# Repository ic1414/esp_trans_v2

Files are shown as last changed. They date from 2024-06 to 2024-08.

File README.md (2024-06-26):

# esp_trans_v2

- [视频介绍](https://www.bilibili.com/video/BV1F94y157EU/?spm_id_from=333.999.0.0)（[旧版遥控](https://www.bilibili.com/video/BV1n44y1s7gA/?spm_id_from=333.999.0.0)）
- [视频组装](https://www.bilibili.com/video/BV1uH4y1w7Zv/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)
- [software doc](./doc/software_tut.md)  
- [hardware doc](./doc/hardware_tut.md)   

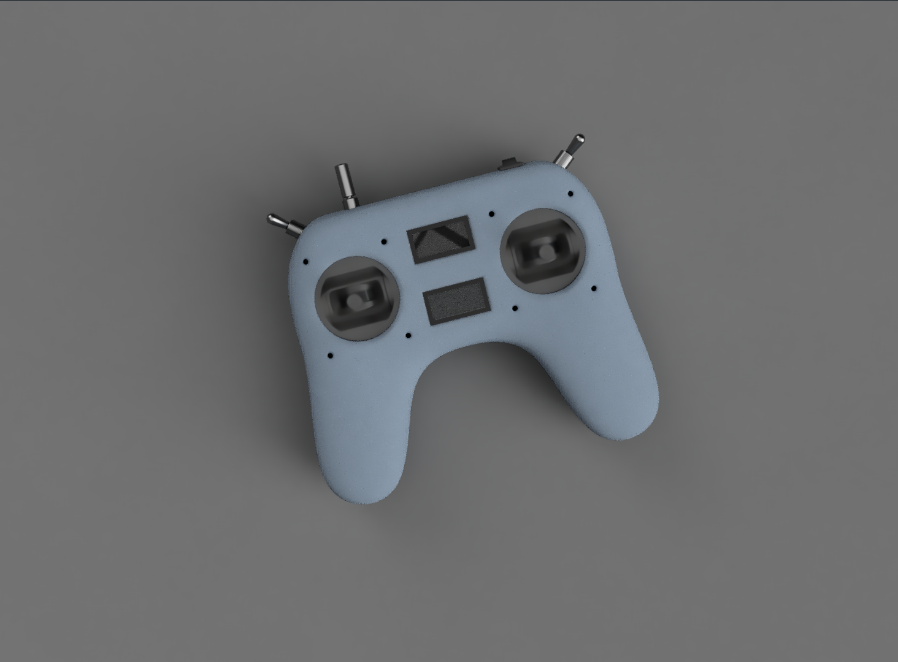
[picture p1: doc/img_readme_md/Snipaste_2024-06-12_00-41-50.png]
esp_trans_v2


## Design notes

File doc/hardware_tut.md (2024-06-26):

- [一些图片](#一些图片)
- [一些文件](#一些文件)
- [焊盘&丝印](#焊盘丝印)
- [pcb 接线图](#pcb-接线图)
- [零件排线长度](#零件排线长度)
- [制作步骤（参考）](#制作步骤参考)
- [注意事项](#注意事项)
- [end](#end)

## 一些图片



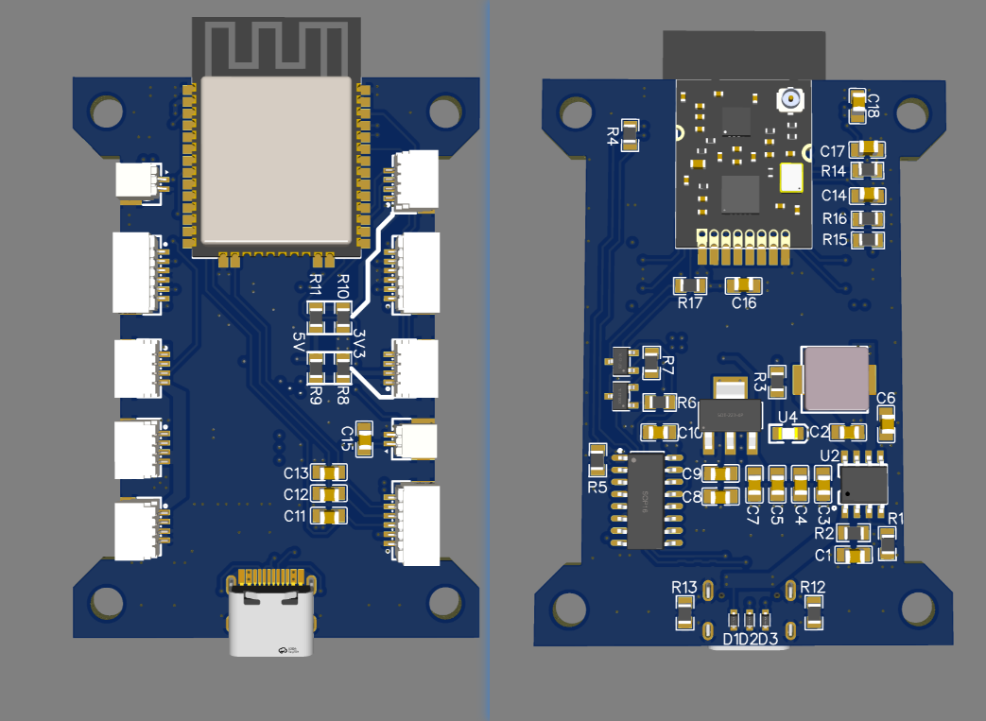
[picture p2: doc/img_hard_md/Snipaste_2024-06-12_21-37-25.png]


## 一些文件

- [购物清单](../pcb/esp_trans_v2_material.xlsx)  
- [3d模型-上半身](../3d%20model/top2.stl)，[3d模型-下半身](../3d%20model/bot2.stl)
- [立创eda 原理图](../pcb/LCEDA_schematic_esp_trans_v2.json)，[pdf 原理图](../pcb/pdf_schematic_esp_trans_v2.pdf)
- [立创eda pcb 源文件](../pcb/LCEDA_PCB_esp_trans_v2.json)，[gerber文件](../pcb/Gerber_PCB_esp_trans_v2.zip)  
- [bom表](../pcb/esp_trans_v2_bom_lite.xlsx)  

## 焊盘&丝印
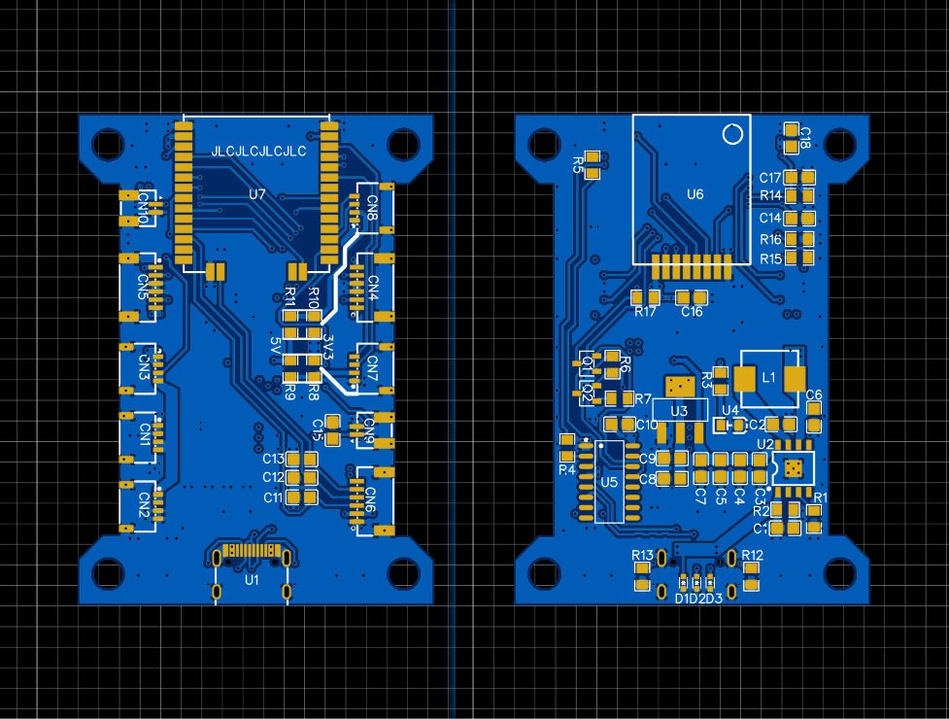
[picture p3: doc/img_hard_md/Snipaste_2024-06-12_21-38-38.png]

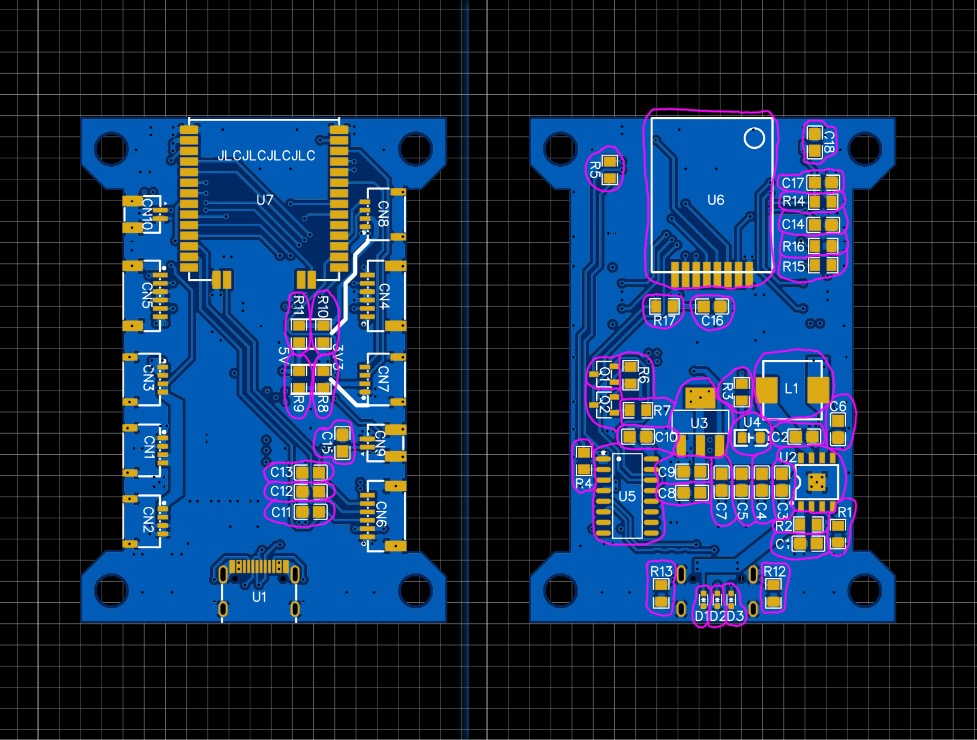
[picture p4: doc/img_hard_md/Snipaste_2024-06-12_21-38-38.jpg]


## pcb 接线图

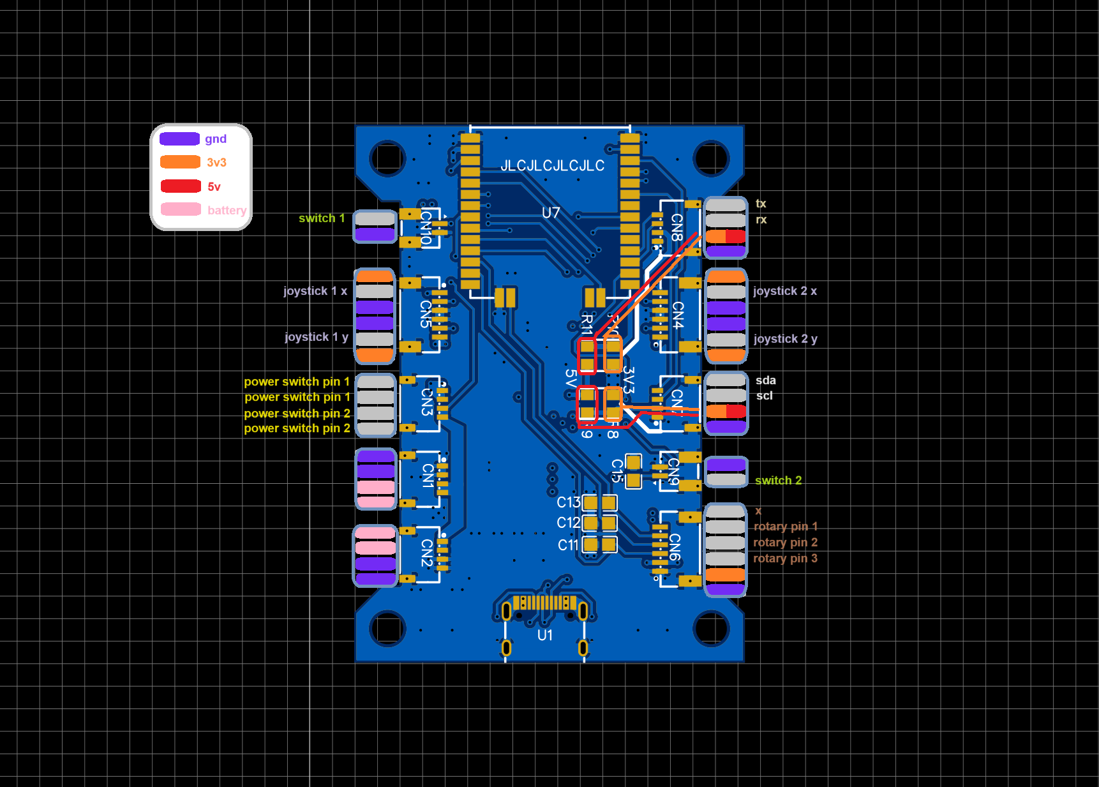
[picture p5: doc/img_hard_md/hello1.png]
  
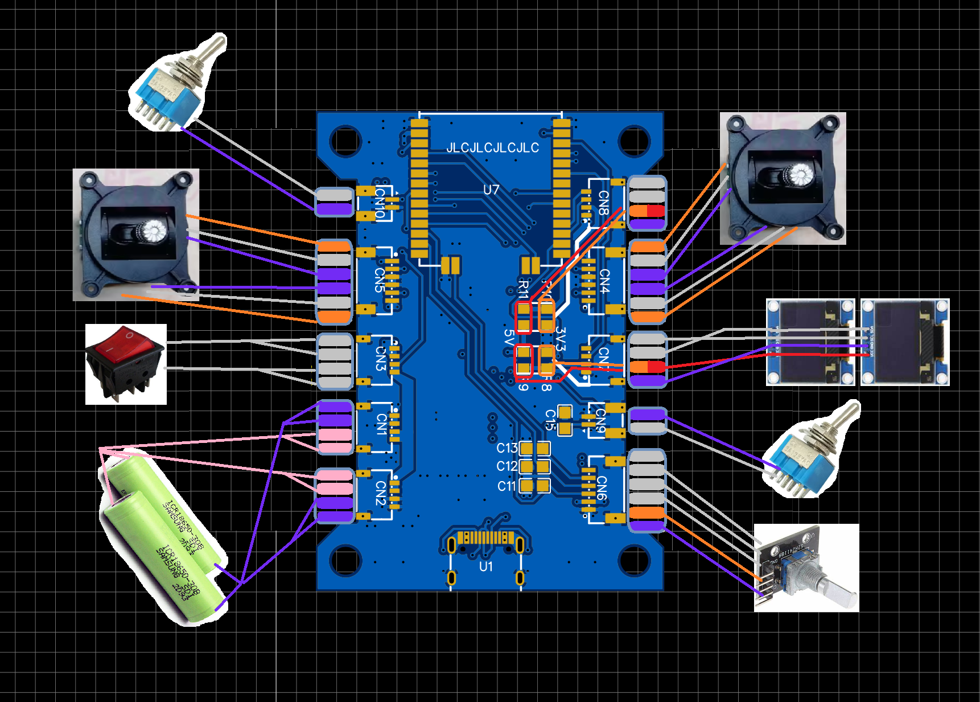
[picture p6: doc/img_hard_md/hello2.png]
  

## 零件排线长度
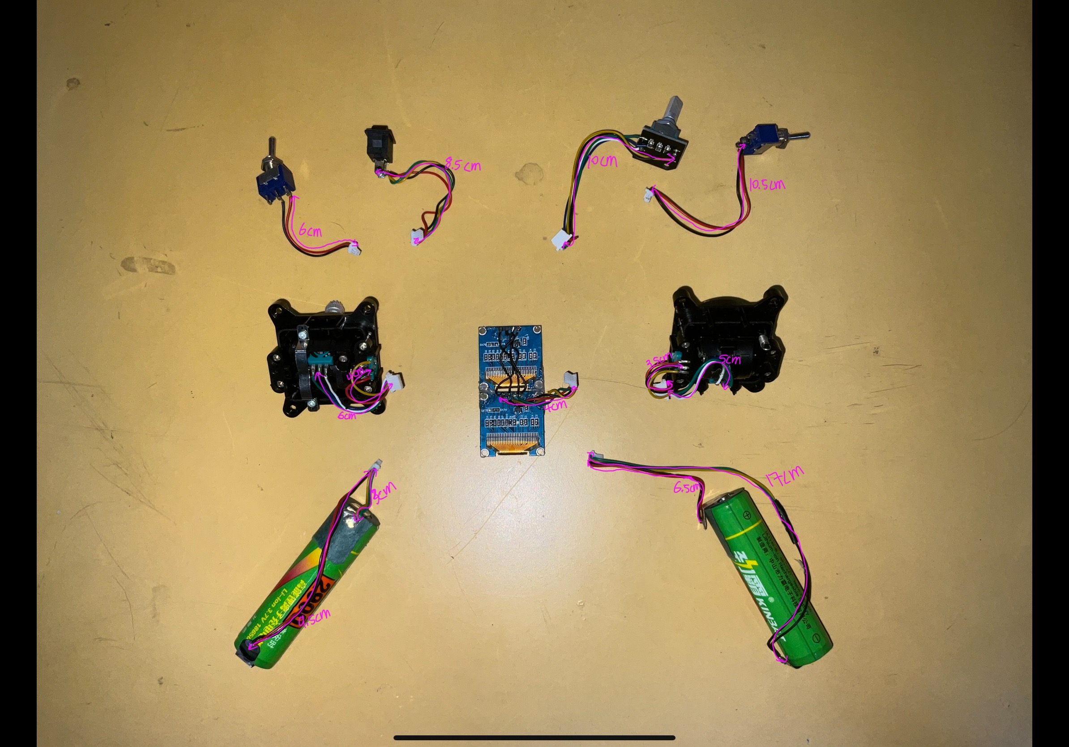
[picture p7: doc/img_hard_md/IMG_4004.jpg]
  

## 制作步骤（参考）

1. 参考[购物清单](../pcb/esp_trans_v2_material.xlsx)购买材料。

2. 去[嘉立创](https://www.jlc.com/portal/)下单pcb。（[gerber文件](../pcb/Gerber_PCB_esp_trans_v2.zip)）

3. 按照 [bom表](../pcb/esp_trans_v2_bom_lite.xlsx)   焊接pcb。

4. 光固化打印外壳。[3d模型-上半身](../3d%20model/top2.stl)，[3d模型-下半身](../3d%20model/bot2.stl)。

5. 参考[pcb 接线图](#pcb-接线图)组装遥控。

## 注意事项
- 你需要取下屏幕模块上的针脚。（如有）  
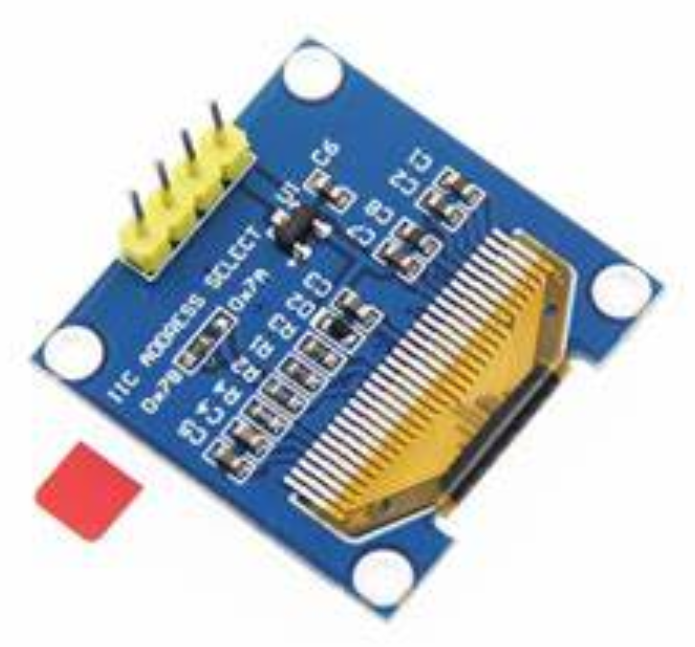
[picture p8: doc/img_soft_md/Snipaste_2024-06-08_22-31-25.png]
  

- 采用 iic 通信的设备使用地址来区分彼此。因为esp32遥控有两块屏幕，所以你需要改变模块背面电阻的位置来改变iic地址。  
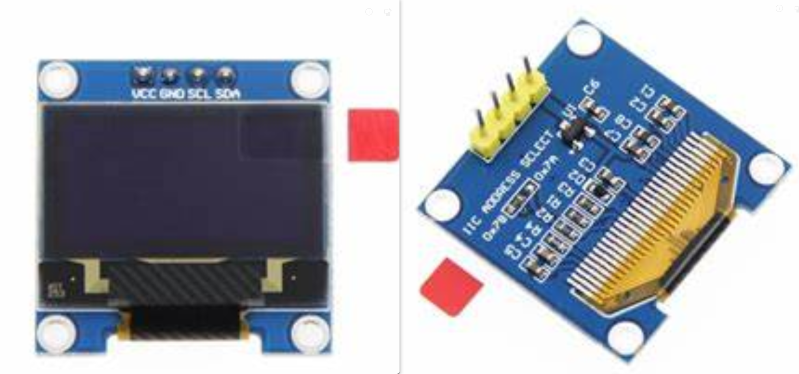
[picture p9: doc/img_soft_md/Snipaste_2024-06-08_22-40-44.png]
  

- 需要对旋转编码器模块的pcb进行裁剪。你可用美工刀刮出一条浅缝，然后双手持钳子将pcb掰断。  
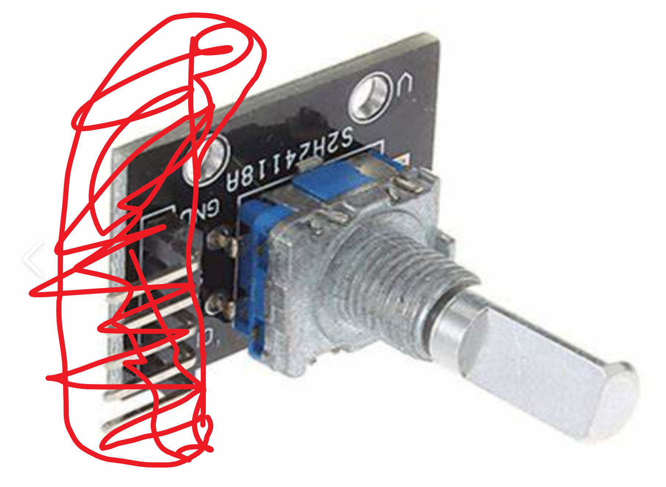
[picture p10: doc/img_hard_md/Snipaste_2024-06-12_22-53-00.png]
  

- 最好选自带保护板的18650电池。  
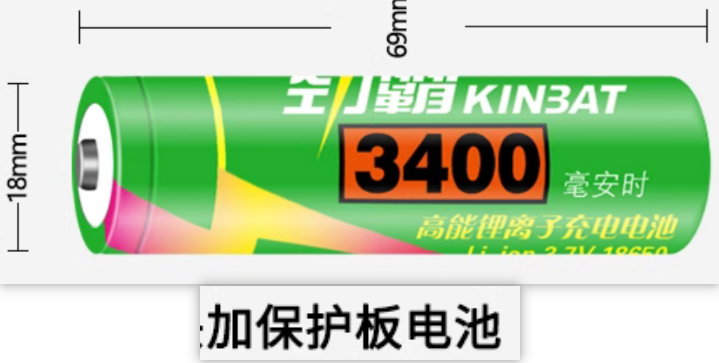
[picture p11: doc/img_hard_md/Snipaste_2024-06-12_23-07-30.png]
  

- 需要将电池正负极引出来。（可以问下店家能不能帮下）  
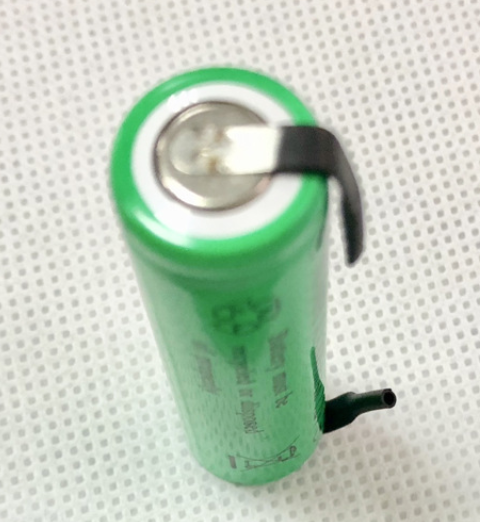
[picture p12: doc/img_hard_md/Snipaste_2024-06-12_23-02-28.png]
  

## end
希望这个文档对大家有帮助。

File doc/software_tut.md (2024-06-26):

- [介绍](#介绍)
- [我需要知道什么](#我需要知道什么)
- [vscode配置](#vscode配置)
- [如何去理解代码](#如何去理解代码)
- [遥控的主要组成](#遥控的主要组成)
  - [0.96 inch oled屏幕](#096-inch-oled屏幕)
  - [航模摇杆](#航模摇杆)
  - [旋转编码器](#旋转编码器)
  - [拨动开关](#拨动开关)
  - [nrf24l01模块](#nrf24l01模块)
  - [菜单和菜单导航](#菜单和菜单导航)
- [源文件里都是什么](#源文件里都是什么)
- [固件烧录](#固件烧录)
- [end](#end)

## 介绍

- 使用 arduino 框架，基于 esp32-wroom-32u 的航模遥控。
- 本文档只提供手把半只手教学，不是保姆级教学哈。
- 在阅读本文档之前，大家可以看下这个关于遥控器的[视频](https://www.bilibili.com/video/BV1F94y157EU/?spm_id_from=333.999.0.0)。  
- 硬件文档在[这里](hardware_tut.md)。  

***
***
***

## 我需要知道什么

在阅读本教程之前最好懂得以下的一些知识。  
- c语言基础（一点点指针）
- 一点点cpp面向对象（不需要继承）
- arduino 基础（点灯，输入，输出）
- 听说过 iic，spi，gpio

***
***
***

## vscode配置

1. vscode 安装 arduino，C/C++，C/C++ Extension Pack 等插件，然后配置编译器。图片步骤在[这里](./img_soft_md/esp_trans_vscode.pdf)

2. 去 arduino board manager (ctrl + shift + p) 搜索并安装 esp32 包。***版本是 2.0.13 ！***。

3. 解压 src/z lib.zip，将里面的库复制到编译器的库文件夹。（在我的电脑里是 C:/Users/user1/Documents/Arduino/libraries/，没有这个文件夹就创建一个）  

4. 打开 src/src.ino。点击右上角的 verify 将自动在./vscode/ 生成 c_cpp_properties.json。 成功的话，你会发现各种报错都消失了。  

5. vscode配置完成！  

***
***
***

## 如何去理解代码

使用 arduino 框架设计一个产品非常的简单，通常情况下我们只要从网上找到产品里各个模块的库，然后像搭积木一样搭起来就可以了。  

接下来我将介绍如何使用esp32遥控的各个模块，相信到最后你可以很快的看懂esp32遥控的全部代码。

***
***
***

## 遥控的主要组成

1. [0.96 inch oled 屏幕模块](#096-inch-oled屏幕)
2. [航模摇杆](#航模摇杆)
3. [旋转编码器](#旋转编码器)
4. [拨动开关](#拨动开关)
5. [nrf24l01模块](#nrf24l01模块)
6. [菜单和菜单导航](#菜单和菜单导航)

***

### 0.96 inch oled屏幕

库的官方例子：[嗨](https://github.com/adafruit/Adafruit_SSD1306/blob/master/examples/ssd1306_128x64_i2c/ssd1306_128x64_i2c.ino)  
连接方式：iic  
注意：采用 iic 通信的设备使用地址来区分彼此。因为esp32遥控有两块屏幕，所以你需要改变模块背面电阻的位置来改变iic地址。  


在 arduino 下使用这款屏幕很简单。一般来说，我们通过变量名就能猜出其作用。我们一起来看下面的代码。
```cpp
#include <Wire.h>
#include <Adafruit_GFX.h>
#include <Adafruit_SSD1306.h>

#define SCREEN_WIDTH 128 // OLED display width, in pixels
#define SCREEN_HEIGHT 64 // OLED display height, in pixels
#define OLED_RESET     -1 // Reset pin # (or -1 if sharing Arduino reset pin)
#define SCREEN_ADDRESS 0x3D
Adafruit_SSD1306 display(SCREEN_WIDTH, SCREEN_HEIGHT, &Wire, OLED_RESET);

void setup() {

    // SSD1306_SWITCHCAPVCC = generate display voltage from 3.3V internally
    display.begin(SSD1306_SWITCHCAPVCC, SCREEN_ADDRESS);

    display.clearDisplay(); // 清空画布，但此时你的屏幕并不会清空，因为还没有“更新”。  
    display.setTextSize(2); // 设置字体大小。  
    display.setCursor(1, 15); // 设置光标的起点坐标。  
    display.println(F("hello world")); // 将 hello world 印在画布上。字母 h 大概在位置（1，15）附近。
    display.display(); // 将画布输出到屏幕，此时你可以看到 hello world 了。
}
```

***

### 航模摇杆

连接方式：模拟输入  
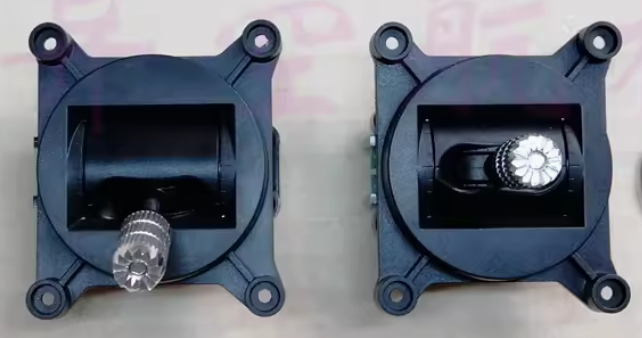
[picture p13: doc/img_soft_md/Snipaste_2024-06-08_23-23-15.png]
  

读取摇杆的位置，其实就是读取电位器的电压。我们只需要使用下面的一行代码即可获取数值。
```cpp
value = analogRead(pin); // esp32 的ADC是12位的，所以 analogRead(pin) 的范围是0-4095。
```

由于ADC的输出带有噪声，我们可以给ADC的数值添加一个一阶低通滤波器。（代码中 0.8 和 0.2 是滤波的参数，可以看下[这篇博客](https://www.cnblogs.com/embInn/p/14038131.html)）
```cpp
// 假设下面的代码每隔 x 毫秒运行一次。
cur_val = analogRead(pin); // cur_val - current value
lpf_val = (float)cur_val * 0.8 + (float)pre_val * 0.2; // lpf_val - low pass filter value。
pre_val = lpf_val; // pre_val - previous value
```

如果电位器的位置有偏移，我们可以用以下代码来修正。（如果你不知道[map()](https://www.arduino.cc/reference/en/language/functions/math/map/)是什么，可以[看这里](https://www.arduino.cc/reference/en/language/functions/math/map/) ）
```cpp
// cali_min_val - 摇杆在最低位的数值
// cali_mid_val - 摇杆在中间的数值
// cali_max_val - 摇杆在最高位的数值
if(lpf_val >= cali_mid_val) return map(lpf_val, cali_mid_val, cali_max_val, 4095/2, 4095);
else return map(lpf_val, cali_min_val, cali_mid_val, 0, 4095/2);
```

如何使用 joystick.h 和 joystick.cpp。
```cpp
// 各种定义可以在 joystick.h 和 joystick.cpp 中找到！！

JOYSTICK_AXIS j_rx;
JOYSTICK_AXIS j_ry;
JOYSTICK_AXIS j_lx;
JOYSTICK_AXIS j_ly;
JOYSTICK joysticks;

void setup()
{
    j_rx.init(pin_joystick1X, invert_joystick1X);
    j_ry.init(pin_joystick1Y, invert_joystick1Y);
    j_lx.init(pin_joystick2X, invert_joystick2X);
    j_ly.init(pin_joystick2Y, invert_joystick2Y);
    joysticks.init(&j_rx, &j_ry, &j_lx, &j_ly);

    Serial.println("calibrate_mid");
    joysticks.calibrate_mid();
    delay(500);
    Serial.println("calibrate_min_max");
    joysticks.calibrate_min_max();
    Serial.println("done");
    delay(500);
}

void loop()
{
    joysticks.update();
    Serial.println(joysticks.get_lx());
    Serial.println(joysticks.get_ly());
    Serial.println(joysticks.get_rx());
    Serial.println(joysticks.get_ry());
    delay(20);
}
```

***

### 旋转编码器

库的官方例子：[嗨](https://github.com/igorantolic/ai-esp32-rotary-encoder/tree/master/examples)  
连接方式：gpio  
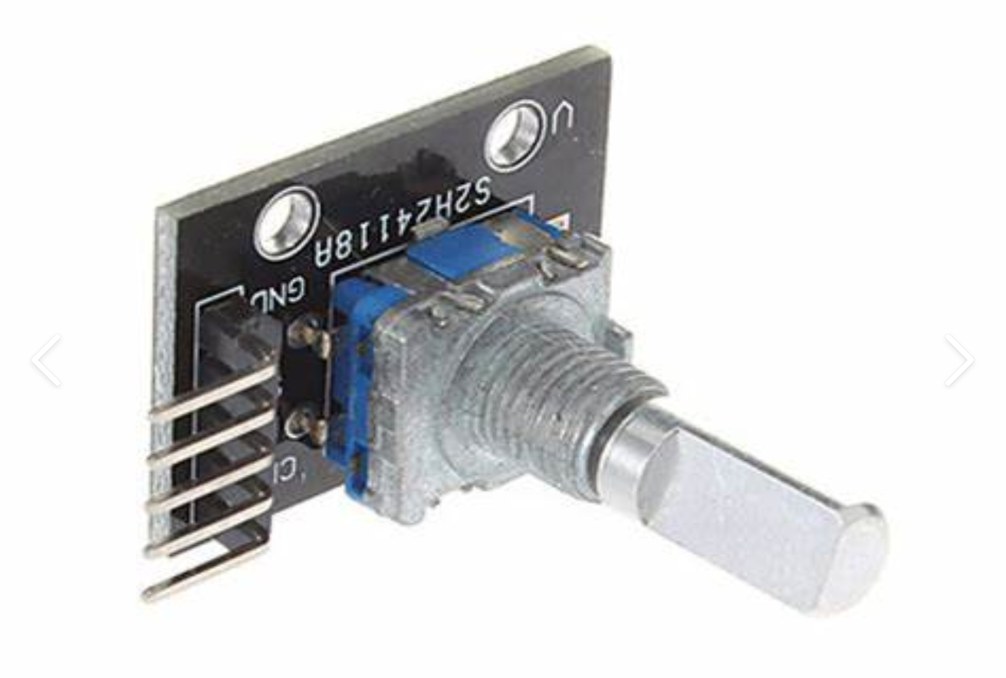
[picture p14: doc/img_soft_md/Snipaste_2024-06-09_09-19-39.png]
   

一个可以旋转和按压的原件，我们转动它来滚动菜单，按压选择菜单。
```cpp
#include <AiEsp32RotaryEncoder.h>
#define pin_rotary_vcc -1
#define rotary_steps 8 // 类似鼠标的灵敏度
AiEsp32RotaryEncoder rotaryEncoder = AiEsp32RotaryEncoder(pin_rotary_a, pin_rotary_b, pin_rotary_button, pin_rotary_vcc, rotary_steps);
void IRAM_ATTR readEncoderISR() { rotaryEncoder.readEncoder_ISR(); } // 设置中断函数。当转动编码器的时候触发中断并更新数值。

void setup()
{
    rotaryEncoder.begin(); // 初始化
    rotaryEncoder.setup(readEncoderISR); // 开启中断
    rotaryEncoder.disableAcceleration(); // 关闭加速度。（设置鼠标和光标的移动距离为线性）
    rotaryEncoder.setBoundaries(0, 0, true); // 设置边界和是否转圈
    rotaryEncoder.reset(); // 重设当前的记录为0
}

void loop()
{
    Serial.println(encoder->readEncoder());
    if (encoder->isEncoderButtonClicked())
    {
        Serial.println("pressed");
    }

    delay(50);
}

```

***

### 拨动开关

连接方式：gpio  
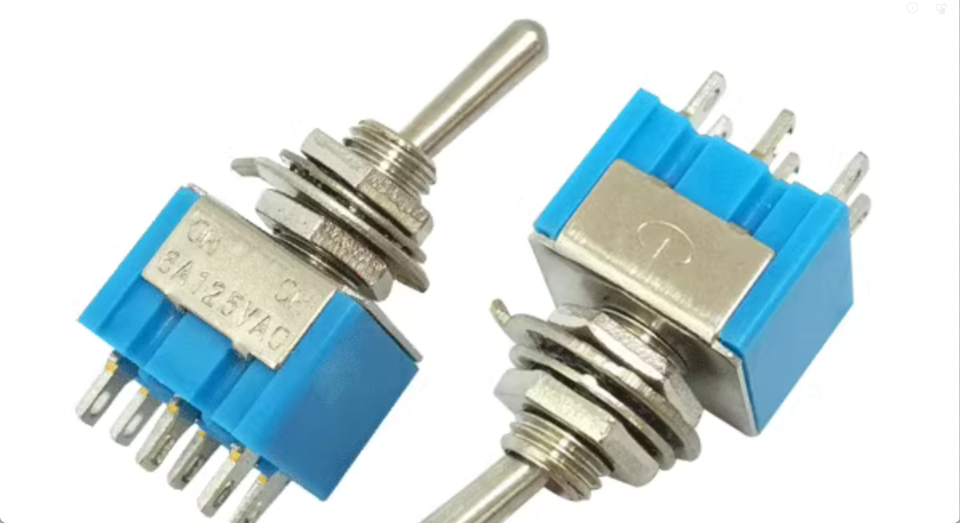
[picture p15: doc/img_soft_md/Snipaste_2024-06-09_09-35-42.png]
   

普通的开关。
```cpp
digitalRead(pin_switch1)
```

***

### nrf24l01模块

库的官方例子：[嗨](https://github.com/nRF24/RF24/tree/master/examples)  
连接方式：SPI  
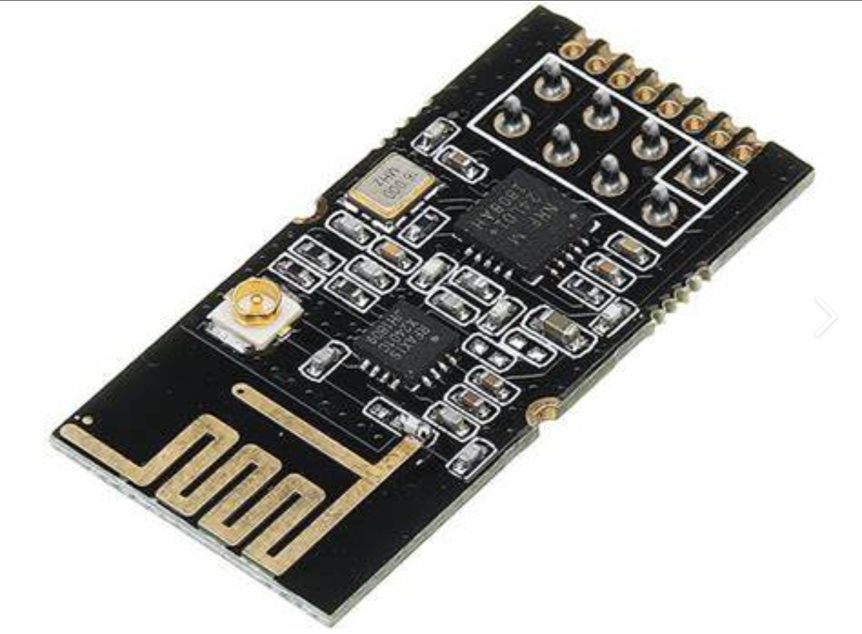
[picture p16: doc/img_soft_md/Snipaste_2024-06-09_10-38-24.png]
   

2.4g 无线收发模块。
```cpp
#define pin_nrf_ce 25
#define pin_nrf_csn 26

RF24 radio(pin_nrf_ce, pin_nrf_csn); // CE, CSN

void setup()
{
    radio.begin();
    radio.enableDynamicPayloads(); 
    radio.enableAckPayload(); //数据回传
    radio.setChannel(1); //设置通道
    radio.openReadingPipe(0, "12345678"); // 接收地址0-"12345678"
    radio.openReadingPipe(1, "82345671"); // 接收地址1-"82345671"
    radio.openWritingPipe("12345678"); // 发送地址-"12345678"
    radio.setPALevel(RF24_PA_MAX); // 设置发送功率。RF24_PA_MAX是一个enum。
    radio.stopListening(); // 停止接收（反过来说就是发送）
}

void loop()
{
    // mydata 可以是任何类型，但是数据的大小不能超过 32 byte。status 记录是否发送成功
    status = radio.write(&mydata, sizeof(mydata));
    
    // 如果发送成功且有数据回传
    if (status && radio.available()) radio.read(&mydata2, sizeof(mydata2));
}
```

***

### 菜单和菜单导航

我们用菜单导航去选择菜单，而一个菜单则会执行我们自定义的功能。从电脑的角度来看的话，这个由菜单和菜单导航组成的系统只有文件夹和可执行程序，没有文本文档。不过我们的菜单可以同时是一个文件夹和可执行程序。

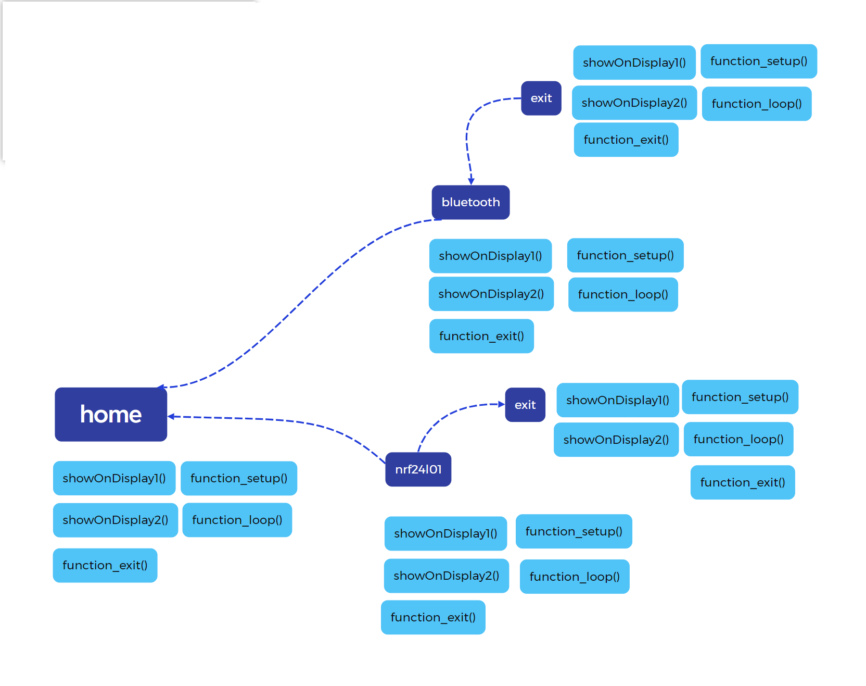
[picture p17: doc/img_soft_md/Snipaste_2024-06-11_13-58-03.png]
   

我们先来了解菜单核心组件的规范。
```cpp
#define mymenu_max_subs 7 // 一个菜单最多可以有7个子菜单

class MYMENU // 菜单
{
    // 函数组 start-------------------------------------------------
    void showOnDisplay1(); // 选中此菜单时在屏幕1显示的画面。
    void showOnDisplay2(); // 当此菜单是选中的菜单的子菜单时在屏幕2显示的画面。
    void function_setup(); // 选中此菜单时运行一次 function_setup() 里的代码。
    void function_loop(); // 选中此菜单时周期性地运行 function_loop() 里的代码。
    void function_exit(); // 退出此菜单时运行一次 function_exit() 里的代码。
    // 函数组 end---------------------------------------------------
    
    MYMENU *parent_menu = NULL; // 此菜单的父级菜单
    MYMENU *submenu_list[mymenu_max_subs] = {NULL}; // 此菜单的子菜单  
};
```

我们设计不同的菜单是为了实现不同的功能，那我们怎么让不同的菜单有不同的函数组呢？使用类的继承好像可以，但在这里我们让每个 MYMENU 的实例去绑定一个自定义的功能函数。
```cpp
// 我们先设计一个功能函数。每个功能函数都有如下的固定格式。我们让 func_test_menu() 的5个case的功能和菜单函数组的功能一一对应。
void func_test_menu(int16_t n)
{
    switch (n)
    {
    case 1: // 选中此菜单时在屏幕1显示的画面。
        break;
    case 2: // 当此菜单是选中的菜单的子菜单时在屏幕2显示的画面。
        break;
    case 3: // 选中此菜单时运行一次 function_setup() 里的代码。
        break;
    case 4: // 选中此菜单时周期性地运行 function_loop() 里的代码。
        break;
    case 5: // 退出此菜单时运行一次 function_exit() 里的代码。
        break;
    }
}

// 现在我们只要把 func_test_menu() 和 菜单绑定即可。
MYMENU test_menu;
test_menu.init(&func_test_menu); // 绑定

// test_menu.showOnDisplay1() == func_test_menu(1)
// 具体的实现可以在 mymenu.h 和 mymenu.cpp 中找到。
```

接下来我们来看 菜单导航 是如何导航的。菜单导航 有两个参数就能开始工作了，一个是起始菜单，另外个是编码器。
```cpp
class NAVI
{
    MYMENU *current_menu = NULL; // 最新被选中的菜单。
    AiEsp32RotaryEncoder *encoder; // 旋转编码器
};
```

我们控制编码器的值的范围在 current_menu 的子菜单数量以内，这样我们就能通过旋转来选择子菜单，按压进入菜单。
```cpp
// .get_num_valid_submenus() - get number of valid submenus

encoder->setBoundaries(0, current_menu->get_num_valid_submenus() - 1, true); // 设置范围
if(/*button pressed*/) current_menu = current_menu->submenu_list[encoder->readEncoder()]；
```

你可能发现了我们这个 菜单导航 好像只能进不能出，因此我们还需要一个特殊的<退出>菜单来实现退出。
```cpp
MYMENU menu_exit;

encoder->setBoundaries(0, current_menu->get_num_valid_submenus() - 1, true); // 设置范围

if(/*button pressed*/)
{
    if(current_menu->submenu_list[encoder->readEncoder()] == menu_exit)
    {
        current_menu = current_menu->parent_menu；
    }else
    {
        current_menu = current_menu->submenu_list[encoder->readEncoder()]
    }
}
```

一些图片  
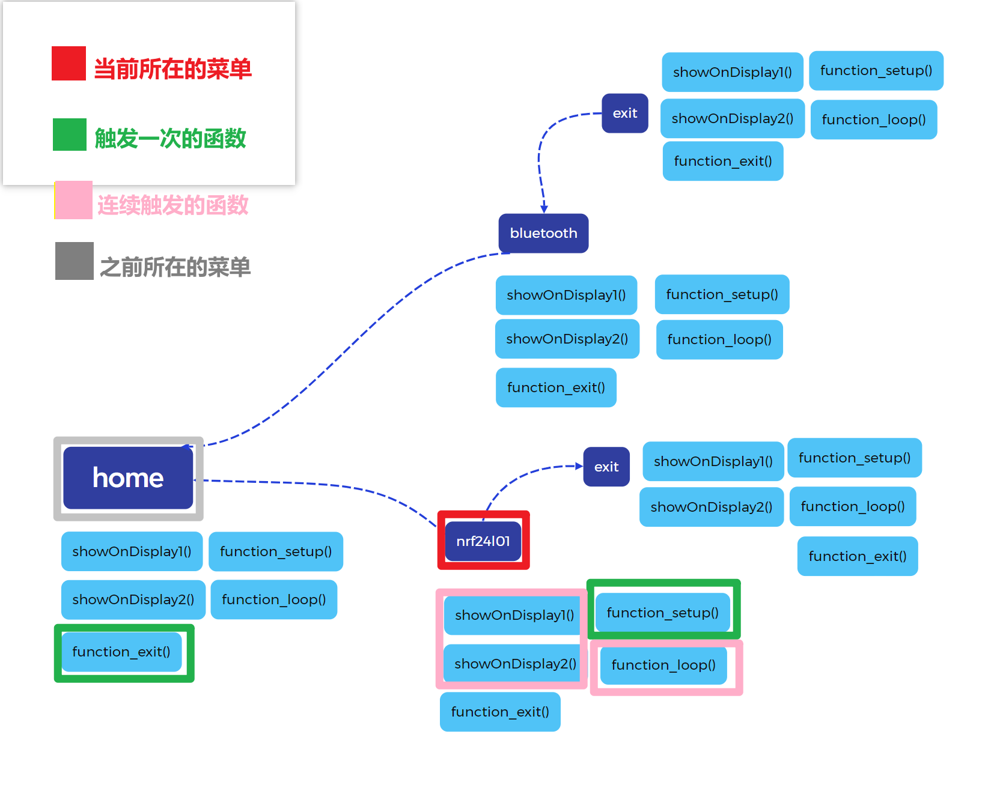
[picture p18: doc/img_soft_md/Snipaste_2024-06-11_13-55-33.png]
   
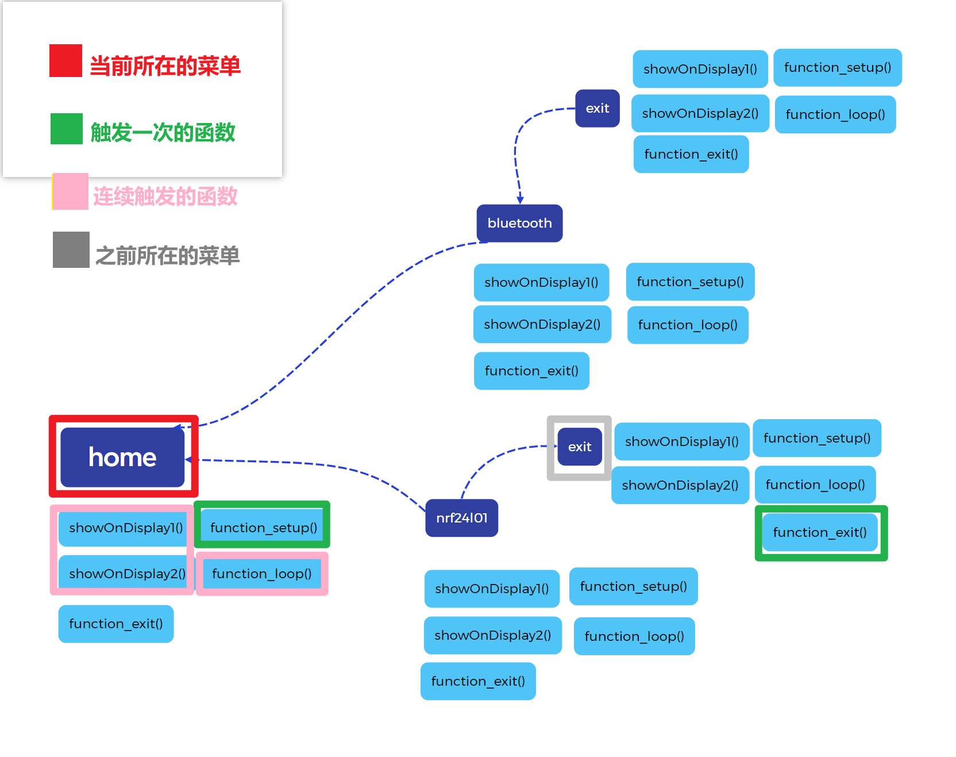
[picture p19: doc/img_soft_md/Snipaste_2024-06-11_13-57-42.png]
   

如何使用  mymenu.h 和 mymenu.cpp 创造一个多级菜单。
- mymenu_a
    - mymenu_b
      - mymenu_exit
    - mymenu_exit
```cpp
// 各种定义可以在 mymenu.h 和 mymenu.cpp 中找到！！

#include "mymenu.h"
#include <AiEsp32RotaryEncoder.h>

MYMENU mymenu_exit;
MYMENU mymenu_a;
MYMENU mymenu_b;

void func_menu_exit(int16_t){}
void func_menu_a(int16_t)
{
    switch (n)
    {
    case 1:
        // show something on display1 when current menu is menu_example
        break;
    case 2:
        // show something on display2 when menu_example is a submenu of current menu
        break;
    case 3:
        // do something once when menu_example is selected
        Serial.println("i am a!");
        break;
    case 4:
        // do something continuously when menu_example is selected
        break;
    case 5:
        // do something once when exit menu_example
        break;
    }
}

void func_menu_b(int16_t)
{
    switch (n)
    {
    case 1:
        // show something on display1 when current menu is menu_example
        break;
    case 2:
        // show something on display2 when menu_example is a submenu of current menu
        break;
    case 3:
        // do something once when menu_example is selected
        Serial.println("i am !b");
        break;
    case 4:
        // do something continuously when menu_example is selected
        break;
    case 5:
        // do something once when exit menu_example
        break;
    }
}

AiEsp32RotaryEncoder rotaryEncoder = AiEsp32RotaryEncoder(pin_rotary_a, pin_rotary_b, pin_rotary_button, pin_rotary_vcc, rotary_steps);
void IRAM_ATTR readEncoderISR() { rotaryEncoder.readEncoder_ISR(); }

NAVI menu_navi; // 菜单导航

void setup(){
    mymenu_exit.init(&func_menu_exit);

    mymenu_a.init(&func_menu_a);
    static MYMENU * alist_mymenu_a[] = {&mymenu_b, &mymenu_exit};
    mymenu_a.set_submenu(alist_mymenu_a, sizeof(alist_mymenu_a)/sizeof(MYMENU *));

    mymenu_b.init(&func_menu_b);
    static MYMENU * alist_mymenu_b[] = {&mymenu_exit};
    mymenu_b.set_submenu(alist_mymenu_b, sizeof(alist_mymenu_b)/sizeof(MYMENU *));

    rotaryEncoder.begin(); // 旋转编码器初始化
    rotaryEncoder.setup(readEncoderISR); // 旋转编码器初始中断
    rotaryEncoder.disableAcceleration(); // 关闭加速度。（如果你突然以很快的速度去移动鼠标，你会发现光标在屏幕上走了很长的距离）
    rotaryEncoder.setBoundaries(0, 0, 1); // 设置 记录变量 的边界和是否转圈。
    rotaryEncoder.reset(); // 重设当前记录变量的值为0

    menu_navi.init(&mymenu_a, &mymenu_exit, &rotaryEncoder);
}

void loop(){
    menu_navi.update();
}
```

***
***
***

## 源文件里都是什么

- {config.h} 一些配置例如管脚，电阻阻值，iic从机地址。  
- {joystick.h/cpp} 自定义的 摇杆 库。
- {mymenu_functions.h/cpp} 功能函数和普通函数的存放位置。
- {mymenu.h/cpp} 自定义的 菜单和菜单导航 库。
- {mynrf.h/cpp} 自定义的 nrf24l01 库。
- {src.ino} 调用各种库组成完整的程序。

***
***
***

## 固件烧录
如果代码验证成功但是烧录失败，你可能需要去操作几下遥控器的拨动开关和编码器。  

拨动开关和编码器使用了 esp32 中的一些特殊管脚，这些管脚控制着 esp32 的启动模式。当 esp32 通电时，你需要控制这些特殊管脚的电平来实现你想要的启动模式。  

关于esp32管脚的使用限制，大家可以去这个[网站](https://randomnerdtutorials.com/esp32-pinout-reference-gpios/)查看，这位作者总结了许多注意事项。

***
***
***

## end
希望这个文档对大家有帮助。

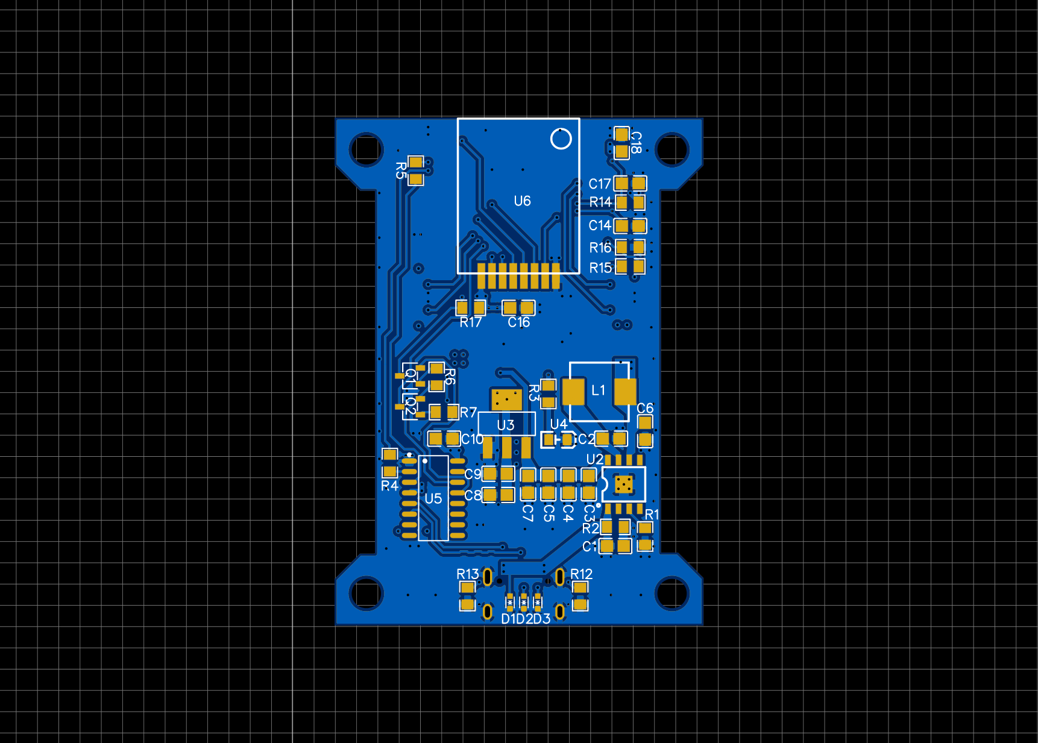
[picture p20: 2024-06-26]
doc/img_hard_md/Snipaste_2024-06-12_13-00-57.png

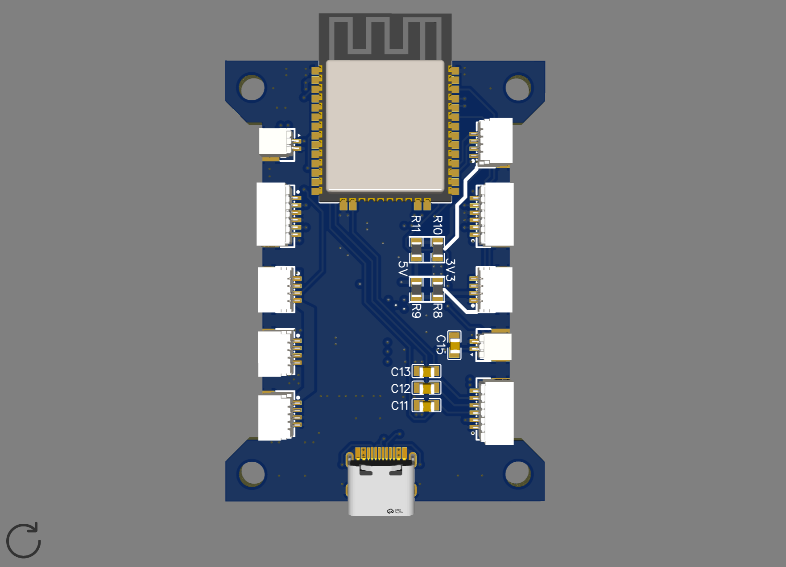
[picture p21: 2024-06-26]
doc/img_hard_md/Snipaste_2024-06-12_13-05-33.png

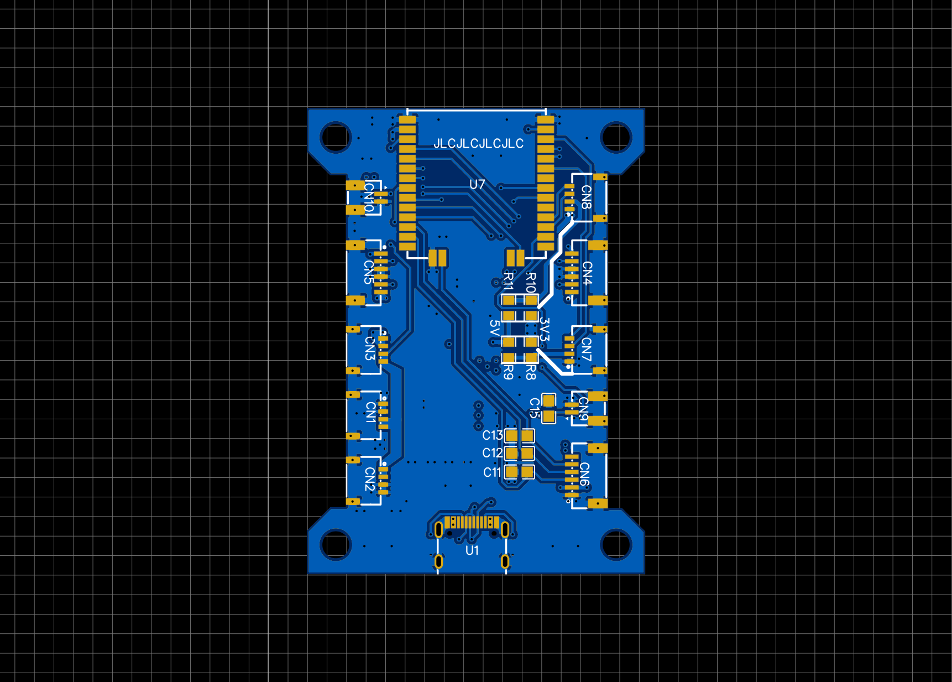
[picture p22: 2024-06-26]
doc/img_hard_md/Snipaste_2024-06-12_13-00-30.png

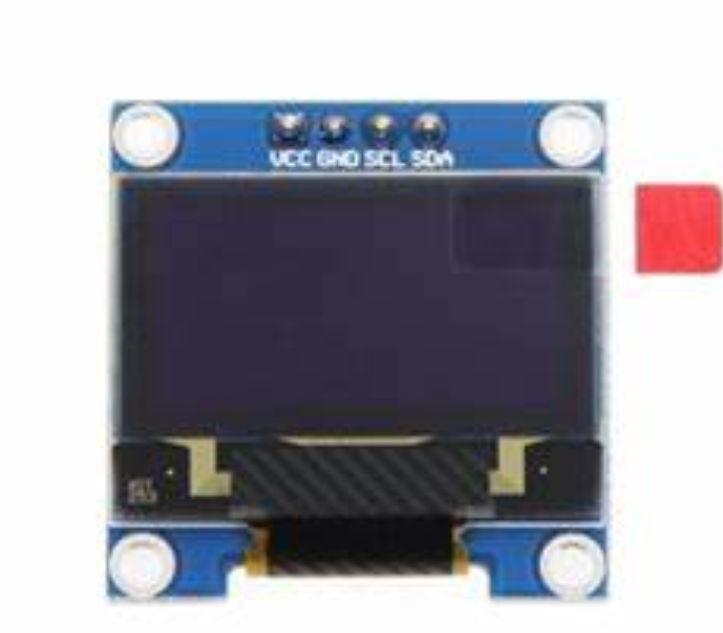
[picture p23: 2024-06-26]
doc/img_soft_md/Snipaste_2024-06-08_22-31-04.png

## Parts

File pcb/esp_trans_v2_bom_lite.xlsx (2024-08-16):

Name | Designator | Quantity
10uF | C1,C6,C7,C9,C16,C18 | 6
100nF | C2,C10,C11,C12,C13,C14,C15,C17 | 8
22uF | C3,C4,C5 | 3
2.2uF | C8 | 1
SH1.0-4P | CN1,CN2,CN3,CN7,CN8 | 5
SH1.0-6P | CN4,CN5,CN6 | 3
SH1.0-2P | CN9,CN10 | 2
LESD5D5.0CT1 | D1,D2,D3 | 3
0630电感 | L1 | 1
SS8050 | Q1,Q2 | 2
51kΩ | R1 | 1
2Ω | R2 | 1
1kΩ | R3,R4,R5 | 3
10kΩ | R6,R7,R14,R17 | 4
5.1kΩ | R12,R13 | 2
4.7kΩ | R15 | 1
3kΩ | R16 | 1
TypeC-16pin | U1 | 1
IP5407 | U2 | 1
BL9110-330BPFB | U3 | 1
0805LED | U4 | 1
CH340C | U5 | 1
GT24-MINI | U6 | 1
ESP32-WROOM-32U(4MB) | U7 | 1

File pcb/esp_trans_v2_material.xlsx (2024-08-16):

物品 | 数量 | 参考链接(参考，参考，参考) | 笔记
3D打印外壳 | 1 | https://www.thingiverse.com/thing:6167664
摇杆 （小摇杆总成） | 2 | https://item.taobao.com/item.htm?id=569565920679&ns=1&abbucket=9&mt=
0.96 OLED | 2 | https://item.taobao.com/item.htm?id=43639171586&ns=1&abbucket=5
18650 (最好加个保护板) | 2 | https://m.tb.cn/h.5SWZRAB?tk=as0OW1MQ5TU | 可以让店家帮忙把正负极引出来
SH1.0-4P 线 | 5 | https://item.taobao.com/item.htm?id=745193272628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
SH1.0-6P 线 | 3 | https://item.taobao.com/item.htm?id=745193272628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
SH1.0 2P 线 | 2 | https://item.taobao.com/item.htm?id=745193272628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
KCD11开关 2档2脚 | 1 | https://item.taobao.com/item.htm?spm=a1z09.2.0.0.63212e8dyYUVGN&id=554500691696&_u=d20f240pupd40f
钮子开关 2档3脚 | 2 | https://item.taobao.com/item.htm?id=557211235711&ns=1&abbucket=5
旋转编码器 长柄 螺纹 | 1 | https://detail.tmall.com/item.htm?_u=d20f240pup59e2&id=620443772113&skuId=4783881330674
螺丝 m2 * 14 + 螺母 | 8 | https://detail.tmall.com/item.htm?_u=e20f240pup423a&id=693685744140&spm=a1z09.2.0.0.4fb92e8d0dxJZt
螺丝 m3 * 12 | 4 | https://detail.tmall.com/item.htm?_u=e20f240pup423a&id=693685744140&spm=a1z09.2.0.0.4fb92e8d0dxJZt
单头六角螺柱 m3 * 11 + 6 | 4 | https://detail.tmall.com/item.htm?_u=e20f240pup68c0&id=633754501371&spm=a1z09.2.0.0.4fb92e8d0dxJZt
注塑铜螺母 m3 * 4 * 4.8 | 4 | https://detail.tmall.com/item.htm?_u=e20f240pup731e&id=635518708353&spm=a1z09.2.0.0.4fb92e8d0dxJZt
SH1.0-4P 卧贴 | 5 | https://detail.tmall.com/item.htm?abbucket=5&id=608413341843&ns=1&spm=a230r.1.14.22.76272789fS2FoL
SH1.0-6P 卧贴 | 3 | https://detail.tmall.com/item.htm?abbucket=5&id=608413341843&ns=1&spm=a230r.1.14.22.76272789fS2FoL
SH1.0 2P 卧贴 | 2 | https://detail.tmall.com/item.htm?abbucket=5&id=608413341843&ns=1&spm=a230r.1.14.22.76272789fS2FoL
LESD5D5.0CT1G | 3 | https://item.taobao.com/item.htm?id=688182096254&ns=1&abbucket=5
0630 1uh | 1 | https://item.taobao.com/item.htm?id=624687278924&ns=1&abbucket=5
S8050 | 2 | https://item.taobao.com/item.htm?id=522573790562&ns=1&abbucket=5
TypeC-16pin | 1 | https://item.taobao.com/item.htm?id=681305774160&ns=1&abbucket=5
IP5407 | 1 | https://item.taobao.com/item.htm?id=675074605636&ns=1&abbucket=5
BL9110-330BPFB | 1 | https://item.taobao.com/item.htm?id=666932581593&ns=1&abbucket=5
CH340C | 1 | https://item.taobao.com/item.htm?id=572355836370&ns=1&abbucket=5
NRF GT24-MINI | 1 | https://item.taobao.com/item.htm?id=575743274440&ns=1&abbucket=5
天线 IPEX 5dbi 50*14 | 1 | https://item.taobao.com/item.htm?spm=a1z09.2.0.0.63212e8dyYUVGN&id=618799041039&_u=d20f240pupf86a
ESP32-WROOM-32U(4MB) | 1 | https://item.taobao.com/item.htm?id=634424428305&ns=1&abbucket=5
0805 51kΩ | 1 | hello
0805 2Ω | 1 | hello
0805 1kΩ | 3 | hello
0805 10kΩ | 4 | hello
0805 5.1kΩ | 2 | hello
0805 4.7kΩ | 1 | hello
0805 3kΩ | 1 | hello
0805 10uF 陶瓷 | 6 | hello
0805 100nF 陶瓷 | 8 | hello
0805 22uF 陶瓷 | 3 | hello
0805 2.2uF 陶瓷 | 1 | hello
0805 LED 可以不要 | 1 | hello

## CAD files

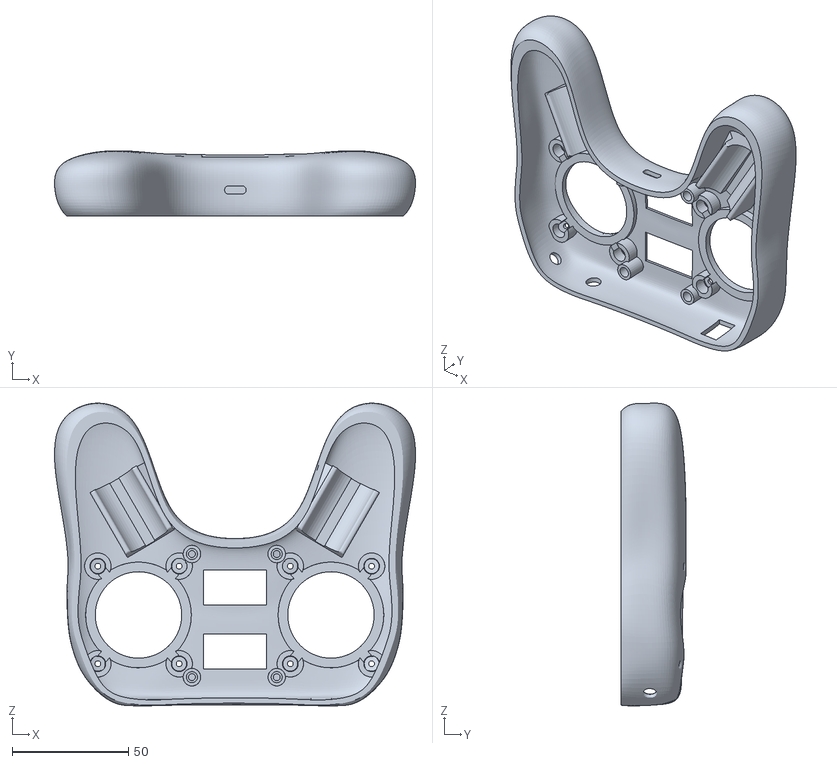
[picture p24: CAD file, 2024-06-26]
3d model/top2.stl
155.4 x 28.2 x 130.3

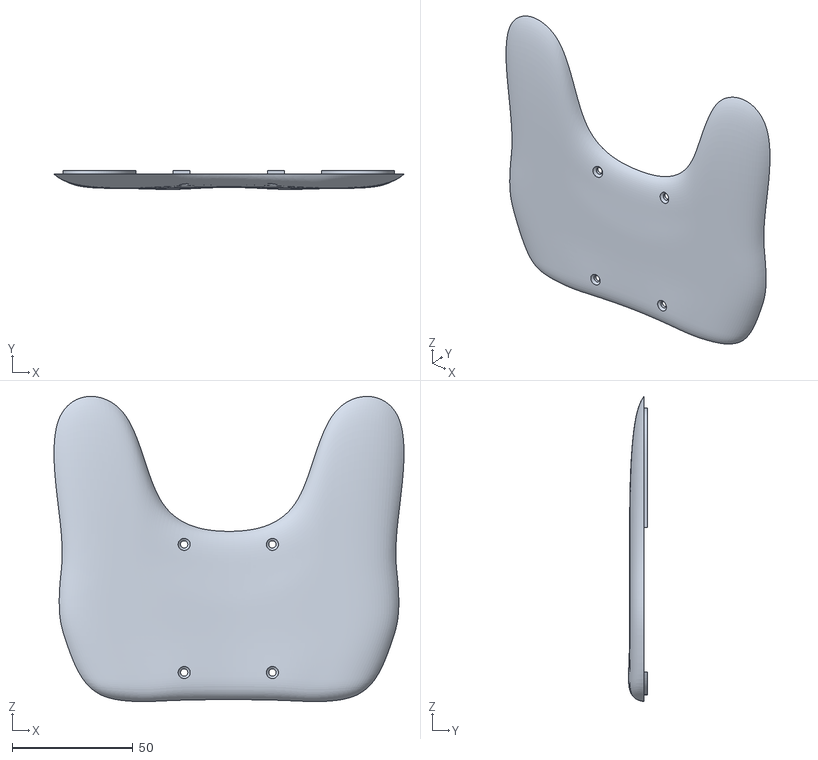
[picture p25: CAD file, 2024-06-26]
3d model/bot2.stl
144.8 x 7.86 x 126.2

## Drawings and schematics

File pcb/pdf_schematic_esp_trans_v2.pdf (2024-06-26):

# joystick esp32-wroom-32u

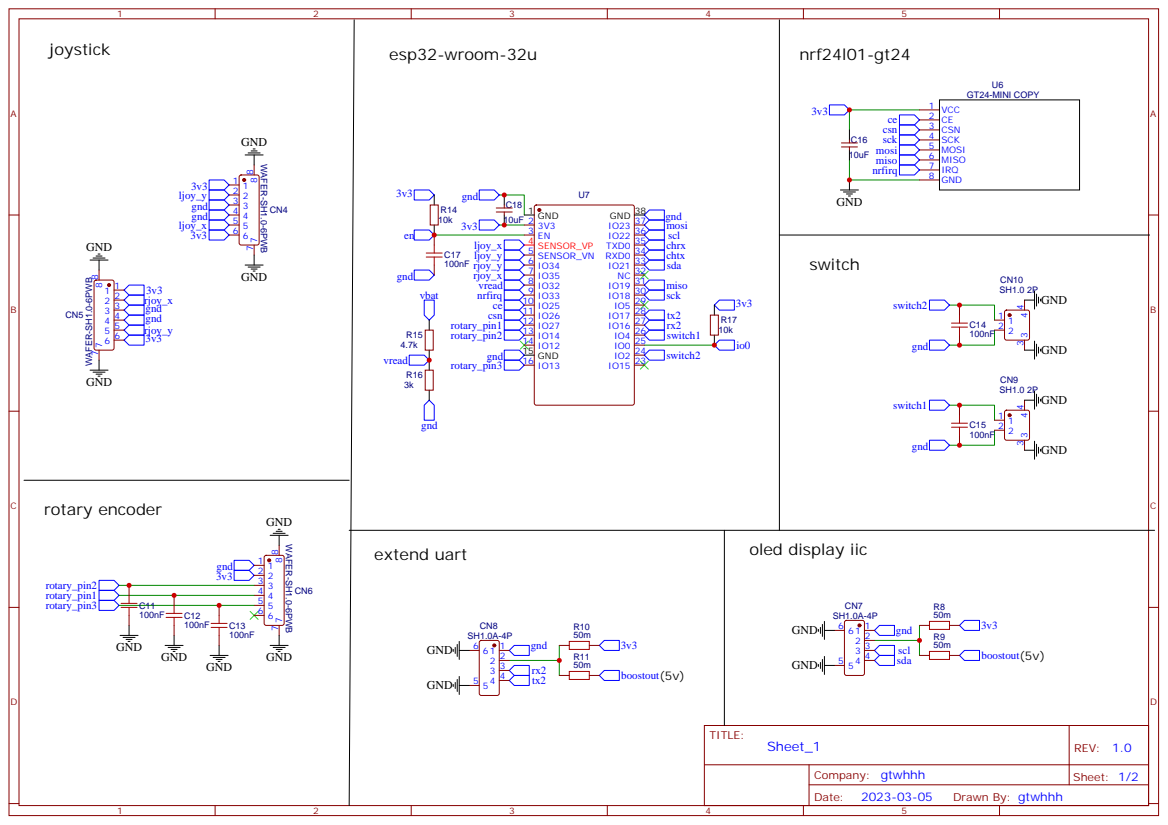
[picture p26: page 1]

type c | battery input
current limit(1 sh1.0 pin) | 0.5A

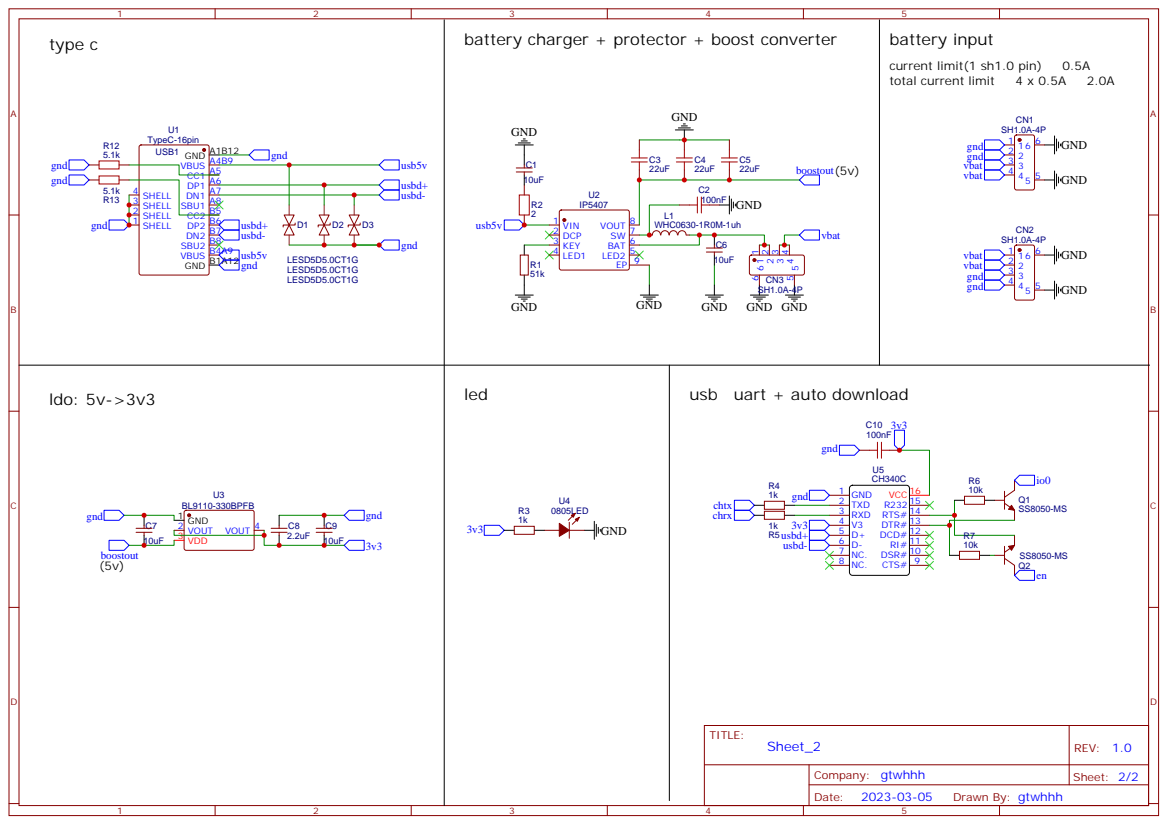
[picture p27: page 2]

battery charger + protector + boost converter

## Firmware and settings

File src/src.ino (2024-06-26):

#include <AiEsp32RotaryEncoder.h>

#include <Wire.h>
#include <Adafruit_GFX.h>
#include <Adafruit_SSD1306.h>

#include "config.h"
#include "joystick.h"
#include "mymenu.h"
#include "mymenu_functions.h"




// joystick--------------------------------------------------------

// j（joystick - 摇杆），r（right - 右），x（x-axis - x轴）
JOYSTICK_AXIS j_rx; // 右手边摇杆x轴
JOYSTICK_AXIS j_ry; // 右手边摇杆y轴
JOYSTICK_AXIS j_lx; // 左手边摇杆x轴
JOYSTICK_AXIS j_ly; // 左手边摇杆y轴
JOYSTICK joysticks; // 将四个摇杆轴打包，方便运算


// rotary encoder---------------------------------------------------
AiEsp32RotaryEncoder rotaryEncoder = AiEsp32RotaryEncoder(pin_rotary_a, pin_rotary_b, pin_rotary_button, pin_rotary_vcc, rotary_steps);
void IRAM_ATTR readEncoderISR() { rotaryEncoder.readEncoder_ISR(); } // 设置中断。当转动编码器的时候触发中断并更新数值。


// iic oled--------------------------------------------------------
Adafruit_SSD1306 display1(oled_width, oled_hight, &Wire, oled_reset);
Adafruit_SSD1306 display2(oled_width, oled_hight, &Wire, oled_reset);


// read battery voltage ----------------------------------------------
// esp32 的cpu是双核的。读取电池电压的函数单独占用一个cpu核心。使用 oversampling（过采样），来获得更高采样分辨率，但会降低采样速度。
TaskHandle_t task_read_batt; // batt - battery
void task_read_batt_code(void *);


// menu -------------------------------------------------------------
// <abc> 表示 abc 是一个特殊菜单。
MYMENU mymenu_exit; // <退出>菜单的作用是返回到当前菜单的父级菜单。除了<退出>和<黑屏>以外的菜单都需要 >=1 的<退出>作为子菜单。
MYMENU mymenu_black; // <黑屏>。这个菜单不能有<退出>。
MYMENU mymenu_home; // 主菜单。（自定义的主页面）
MYMENU mymenu_bl; // 遥控通过蓝牙连接电脑。（自定义的菜单）
MYMENU mymenu_cali; // 校准遥控的摇杆。（自定义的菜单）
MYMENU mymenu_nrf; MYMENU mymenu_nrf_d1; MYMENU mymenu_nrf_d2; // 使用nrf24l01模块收发2.4g无线电。（自定义的菜单）


NAVI menu_navi; // 菜单导航




//------------------------------------------------------------
void setup()
{

    mymenu_exit.init(&func_menu_exit);

    // 在这里开始设置你的菜单------------------------------------------------------------------------------------------------
    // --------------------------------------------------------------------------------------------------------------------

    // 自定义菜单（bl）绑定对应的五合一函数。将<退出>设为自定义菜单（bl）的子菜单。
    mymenu_bl.init(&func_menu_bl); 
    static MYMENU * alist_mymenu_bl[] = {&mymenu_exit};
    mymenu_bl.set_submenu(alist_mymenu_bl, sizeof(alist_mymenu_bl)/sizeof(MYMENU *));

    // 自定义菜单（nrf_d1, nrf_d2）绑定对应的五合一函数。并将<退出>设为自定义菜单（nrf_d1, nrf_d2）的子菜单。
    static MYMENU * alist_mymenu_nrf_dx[] = {&mymenu_exit};
    mymenu_nrf_d1.init(&func_menu_nrf_device1); mymenu_nrf_d1.set_submenu(alist_mymenu_nrf_dx, sizeof(alist_mymenu_nrf_dx)/sizeof(MYMENU *));
    mymenu_nrf_d2.init(&func_menu_nrf_device2); mymenu_nrf_d2.set_submenu(alist_mymenu_nrf_dx, sizeof(alist_mymenu_nrf_dx)/sizeof(MYMENU *));
    // 自定义菜单（nrf）绑定对应的五合一函数。 并将 <退出>，nrf_d1，nrf_d2 设为自定义菜单 nrf 的子菜单。
    static MYMENU * alist_mymenu_nrf_main[] = {&mymenu_nrf_d1, &mymenu_nrf_d2, &mymenu_exit, &mymenu_exit};
    mymenu_nrf.init(&func_menu_nrf); mymenu_nrf.set_submenu(alist_mymenu_nrf_main, sizeof(alist_mymenu_nrf_main)/sizeof(MYMENU *));

    // hello
    static MYMENU * alist_mymenu_cali[] = {&mymenu_exit};
    mymenu_cali.init(&func_menu_cali); mymenu_cali.set_submenu(alist_mymenu_cali, sizeof(alist_mymenu_cali)/sizeof(MYMENU *));

    // world
    static MYMENU * alist_mymenu_home[] = {&mymenu_bl, &mymenu_nrf, &mymenu_cali, &mymenu_exit, &mymenu_exit};
    mymenu_home.init(&func_menu_home); mymenu_home.set_submenu(alist_mymenu_home, sizeof(alist_mymenu_home)/sizeof(MYMENU *));

    // 。
    static MYMENU * alist_mymenu_black[] = {&mymenu_home};
    mymenu_black.init(&func_menu_black); mymenu_black.set_submenu(alist_mymenu_black, sizeof(alist_mymenu_black)/sizeof(MYMENU *));
    //--------------------------------------------------------------------------------------------------------------------
    //--------------------------------------------------------------------------------------------------------------------

    // esp32 有两个cpu核心。arduino的代码在核心0上面运行。我们将电压采样函数绑定到cpu核心1。
    xTaskCreatePinnedToCore(task_read_batt_code, "task_read_batt", 10000, NULL,  1, &task_read_batt, 0);

    // hello world
    Serial.begin(250000);


    // j（joystick - 摇杆），r（right - 右），x（x-axis - x轴）
    pinMode(pin_switch1, INPUT_PULLUP); // 设置拨动开关
    pinMode(pin_switch2, INPUT_PULLUP); // 设置拨动开关
    j_rx.init(pin_joystick1X, invert_joystick1X); // 初始化摇杆
    j_ry.init(pin_joystick1Y, invert_joystick1Y); // 初始化摇杆
    j_lx.init(pin_joystick2X, invert_joystick2X); // 初始化摇杆
    j_ly.init(pin_joystick2Y, invert_joystick2Y); // 初始化摇杆
    joysticks.init(&j_rx, &j_ry, &j_lx, &j_ly); // 初始化摇杆们

    rotaryEncoder.begin(); // 旋转编码器初始化
    rotaryEncoder.setup(readEncoderISR); // 旋转编码器初始中断
    rotaryEncoder.disableAcceleration(); // 关闭加速度。（如果你突然以很快的速度去移动鼠标，你会发现光标在屏幕上走了很长的距离）
    rotaryEncoder.setBoundaries(0, 0, 1); // 设置 记录变量 的边界和是否转圈。
    rotaryEncoder.reset(); // 重设当前记录变量的值为0

    // 菜单导航
    menu_navi.init(&mymenu_home, &mymenu_exit, &rotaryEncoder);

    // display begin
    display1.begin(SSD1306_SWITCHCAPVCC, oled_address1);
    display2.begin(SSD1306_SWITCHCAPVCC, oled_address2);

    // set display brightness
    display1.setTextColor(SSD1306_WHITE); display2.setTextColor(SSD1306_WHITE);
    display1.ssd1306_command(SSD1306_SETCONTRAST); display1.ssd1306_command((byte)10);
    display2.ssd1306_command(SSD1306_SETCONTRAST); display2.ssd1306_command((byte)10);

    // 清除显示屏上的内容。
    display1.clearDisplay(); display1.display();
    display2.clearDisplay(); display2.display();

    // 在屏幕1上显示 press to unlock
    display1.setTextSize(2); display1.setCursor(1, 15);
    display1.println(F("press to\nunlock"));
    display1.display();

    // 当按下旋转编码器解锁遥控。
    while (not(rotaryEncoder.isEncoderButtonClicked())){}

    // 清除显示屏上的内容。
    display1.clearDisplay(); display1.display(); 
    display2.clearDisplay(); display2.display();
}


//------------------------------------------------------------
void loop()
{   
    joysticks.update();
    menu_navi.update();
}




// 电压采样task
void task_read_batt_code(void *pvParameters)
{
  for(;;){
    func_read_batt_v();
    vTaskDelay(1); // 用delay重设下看门狗防止esp32报错/重启。
  }
}

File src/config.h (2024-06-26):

#ifndef config_h
#define config_h



// joystick---------------------------------------------------------------------
#define pin_joystick1X 36
#define invert_joystick1X false

#define pin_joystick1Y 39
#define invert_joystick1Y false

#define pin_joystick2X 34
#define invert_joystick2X true

#define pin_joystick2Y 35
#define invert_joystick2Y true

#define serial_print_joy false // serial print values of joysticks 

// switch-------------------------------------------------------------------------
#define pin_switch1 2
#define pin_switch2 4

// bluetooth gamepad---------------------------------------------------------------
#define gamepad_name "gtwhhh gamepad"
#define gamepad_manufactor "gtwhhh"

// rotary encoder------------------------------------------------------------------
#define pin_rotary_a 27 // any intput pin with interrupt
#define pin_rotary_b 13 // any intput pin with interrupt
#define pin_rotary_button 14 // any intput pin with interrupt
#define pin_rotary_vcc -1 // 不使用gpio供电，用电源（3v3）供电。
#define rotary_steps 8 // 旋转灵敏度

// read battery voltage-------------------------------------------------------------
#define pin_battery 32
#define vDivider_lowR 3.0 // voltage devider low side resistor
#define vDivider_highR 4.7 // voltage devider high side resistor
#define serial_print_batt 1 // serial print bettery voltage

// nrf24l001-----------------------------------------------------------------------
// use default spi pins of esp32 wroom, no need to define
#define pin_nrf_ce 25
#define pin_nrf_csn 26

// oled--------------------------------------------------------------------
// use default iic pins of esp32 wroom, no need to define
#define oled_width 128
#define oled_hight 64
#define oled_reset -1
#define oled_address1 0x3C // iic address
#define oled_address2 0x3D // iic address

#endif
